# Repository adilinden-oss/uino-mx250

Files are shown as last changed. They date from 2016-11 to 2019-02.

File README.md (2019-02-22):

## \*uino-mx250

The \*uino-mx250 was designed for my son Mathew. As a mostly though-hole design, it should be easy to assemble even for a beginner.  The only surface mount component is the micro USB connector. Personally I much prefer micro USB over the full sized or mini connector. Unfortunately I was unable to find a through-hole micro USB.  Having the one surface mounted component was a compromise I was willing to take.

The board uses the PIC32MX250F128B which is available in a 28 pin through-hole package and includes an on-board USB peripheral.  The PIC32MX250F128B is supported by [chipKIT Core](http://chipkit.net/wiki/index.php?title=ChipKIT_core) for the [Arduino](https://www.arduino.cc/) development environment.  Select the chipKIT DP32.

### Important Note

PCB have been ordered from SeeedStudio FusionPCB service. There is no working sample yet.

### Licensing

This work is licensed under a Creative Commons Attribution-ShareAlike 3.0 Unported License, CC BY-SA.

You are free to copy, distribute and transmit the work. You must attribute the work in the manner specified by the author or licensor (but not in any way that suggests that they endorse you or your use of the work). you alter, transform, or build upon this work, you may distribute the resulting work only under the same or similar license to this one.  

Please refer to [http://creativecommons.org/licenses/by-sa/3.0/] for the license.

### Credit

The \*uino-mx250 is derived from previous work done by:

- The [chipKIT DP32](https://reference.digilentinc.com/chipkit_dp32/refmanual)
- The [HelvePic32](http://www.mathias-wilhelm.de/arduino/embedded-boards/helvepic32)

### Details

Aside from teaching my son how to solder, the motivation for the \*uino-mx250 was to create a through-hole chipKIT board that can make use of existing shields.  The \*uino-mx250 is intended to operate at 3.3V as this is the operating voltage of the PIC32MX250F128B.

Mostly due to the use of the USB peripheral, the PIC32MX250F128B has less available I/O than the ATmega328P. Some compromises and choices were necessary to map the PIC32MX250F128B I/O to the shield pins.  In particular analog pins A1, A2, A3, A4 and A5 are directly connected to digital pins D12, D10, D11, D9 and D8.  This is important to remember!

PIC32MX250F128B I/O is mapped to shield pins to preserve the special functions of the digital pins.  Thanks to PIC32 mappable peripheral pins I2C, SPI, serial and PWM functions are were they should be. Still, some compromises were necessary, either D3 or D11 can use OC2 for PWM, but not both at the same time.

### Pin Mapping

```
        PIC32MX250F128B                                     Peripheral
D0      SOSCO/RPA4/T1CK/CTED9/PMA1/RA4                      RX1         RxD
D1      TDI/RPB7/CTED3/PMD5/INT0/RB7                        TX1         TxD
D2      PGED3/RPB5/PMD7/RB5
D3      TCK/RPB8/SCL1/CTED10/PMD4/RB8                       OC2         PWM
D4      TDO/RPB9/SDA1/CTED4/PMD3/RB9
D5      SOSCI/RPB4/RB4                                      OC1         PWM
D6      AN11/RPB13/CTPLS/PMRD/RB13                          OC4/5       PWM
D7      AN9/C3INA/RPB15/SCK2/CTED6/PMCS1/RB15

D8  A5  AN5/C1INA/C2INC/RTCC/RPB3/SCL2/RB3 
D9  A4  AN4/C1INB/C2IND/RPB2/SDA2/CTED13/RB2                OC4/5       PWM
D10 A2  PGED1/AN2/C1IND/C2INB/C3IND/RPB0/RB0                OC3         PWM
D11 A3  PGEC1/AN3/C1INC/C2INA/RPB1/CTED12/RB1               OC2 DO1     PWM MOSI
D12 A1  PGEC3/VREF-/CVREF-/AN1/RPA1/CTED2/PMD6/RA1          DI          MISO
D13     CVREFOUT/AN10/C3INB/RPB14/SCK1/CTED5/PMWR/RB14      SCK1        SCK

A0      PGED3/VREF+/CVREF+/AN0/C3INC/RPA0/CTED1/PMD7/RA0
A1 D12  PGEC3/VREF-/CVREF-/AN1/RPA1/CTED2/PMD6/RA1
A2 D10  PGED1/AN2/C1IND/C2INB/C3IND/RPB0/RB0
A3 D11  PGEC1/AN3/C1INC/C2INA/RPB1/CTED12/RB1
A4 D9   AN4/C1INB/C2IND/RPB2/SDA2/CTED13/RB2                SDA2        SDA
A5 D8   AN5/C1INA/C2INC/RTCC/RPB3/SCL2/RB3                  SCL2        SCL

```

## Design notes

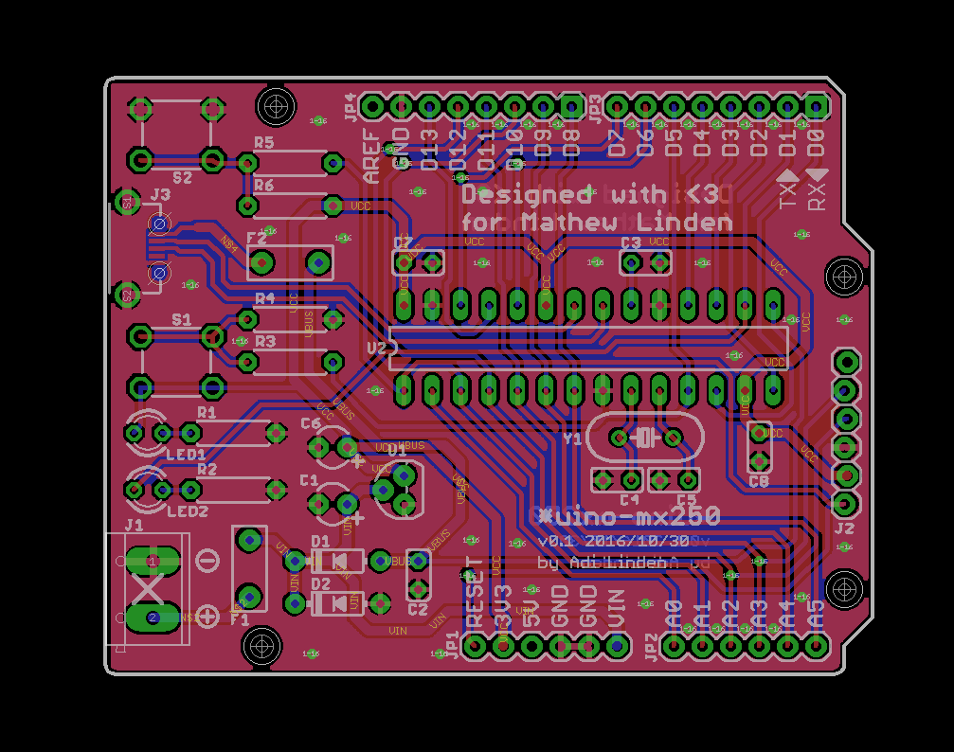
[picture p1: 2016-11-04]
uino-mx250-brd.png

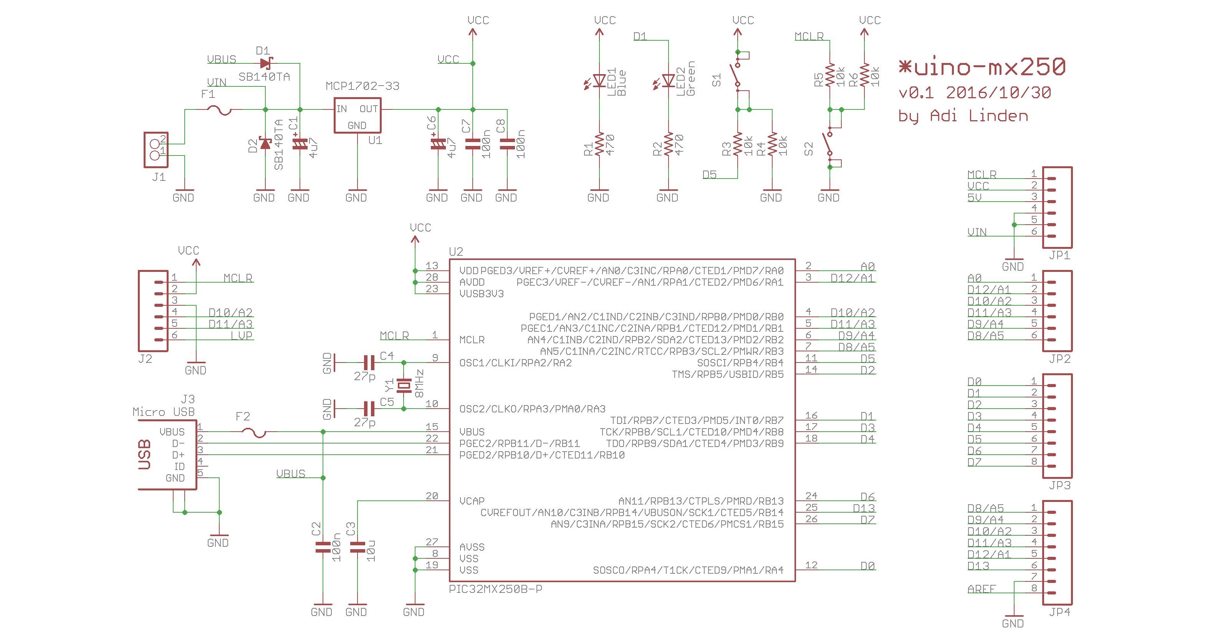
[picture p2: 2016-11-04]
uino-mx250-sch.png

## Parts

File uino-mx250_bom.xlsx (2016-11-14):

Parts | Qty | Value | Manufacturer Part Number | DigiKey Part Number | Package | Description
C1, C6 | 2 | 4u7 | TAP475M010SCS | 478-8841-ND | 2.5mm | 4.7µF ±20% Conformal Coated Tantalum Capacitors 10V Radial 8 Ohm
C2, C7, C8 | 3 | 100n | K104Z15Y5VF5TL2 | BC1160CT-ND | 2.5mm | 0.10µF -20%, +80% 50V Ceramic Capacitor Y5V (F) Radial
C3 | 1 | 10u | FK16X7R1C106K | 445-8348-ND | C025-040X018 | 10µF ±10% 16V Ceramic Capacitor X7R Radial
C4, C5 | 2 | 22p | K220J15C0GF5TL2 | BC1005CT-ND | C025-040X018 | 22pF ±5% 50V Ceramic Capacitor C0G, NP0 Radial
D1, D2 | 2 | 1A | SB140TA | 1655-1514-1-ND | DO-41 | Diode Schottky 40V 1A Through Hole DO-41
F1, F2 | 2 | 400mA | 0ZRC0040FF1E | 507-1335-ND | 5mm | PTC Resettable Fuse 90V 400mA Ih Through Hole Radial, Disc
J1 | 1 | CON_TERMINAL_BLOCK_02-5MM | OSTTC022162 | ED2609-ND | 5mm | 2 Position Wire to Board Terminal Block Horizontal with Board 0.200" (5.08mm) Through Hole
J2 | 1 | Header 1x6 | M20-9990645 | 952-2269-ND | 1X06 | 6 Positions Header, Unshrouded, Breakaway Connector 0.100" (2.54mm) Through Hole Gold
J3 | 1 | Micro USB | 475890001 | WM17143CT-ND | ZX62D-AB-5P8 | USB - micro AB Receptacle Connector 5 Position Surface Mount, Right Angle, Horizontal
JP1, JP2 | 2 | Header 1x6 | PPTC061LFBN-RC | S7004-ND | 1X06 | 6 Position Header Connector 0.100" (2.54mm) Through Hole Tin
JP3, JP4 | 2 | Header 1x8 | PPTC081LFBN-RC | S7006-ND | 1X08 | 8 Position Header Connector 0.100" (2.54mm) Through Hole Tin
LED1 | 1 | Red | 151033RS03000 | 732-5013-ND | LED3MM | Red 621nm LED Indication - Discrete 2V Radial
LED2 | 1 | Green | HLMP1540 | 1080-1046-ND | LED3MM | Green LED Indication - Discrete 2.2V Radial
R1, R2 | 2 | 470 | CF14JT470R | CF14JT470RCT-ND | 0207/7 | RES 470 OHM 1/4W 5% CARBON FILM
R3, R4, R5, R6 | 4 | 10k | CF14JT10K0 | CF14JT10K0CT-ND | 0207/7 | RES 10K OHM 1/4W 5% CARBON FILM
S1, S2 | 2 | Tactile Switch | 1825910-6 | 450-1650-ND | TL1100X | Tactile Switch SPST-NO Top Actuated Through Hole
U1 | 1 | MCP1702-33 | MCP1702-3302E/TO | MCP1702-3302E/TO-ND | TO-92 | Linear Voltage Regulator IC Positive Fixed 1 Output 3.3V 250mA TO-92-3
U2 | 1 | PIC32MX250B-I/SP | PIC32MX270F256B-I/SP | PIC32MX270F256B-I/SP-ND | DIL28-3 | MIPS32® M4K™ PIC® 32MX Microcontroller IC 32-Bit 40MHz 256KB (256K x 8) FLASH 28-SPDIP
Y1 | 1 | 8MHz | ABL-8.000MHZ-B2 | 535-9062-ND | HC49/S | 8MHz ±20ppm Crystal 18pF 80 Ohm -20°C ~ 70°C Through Hole HC49/US

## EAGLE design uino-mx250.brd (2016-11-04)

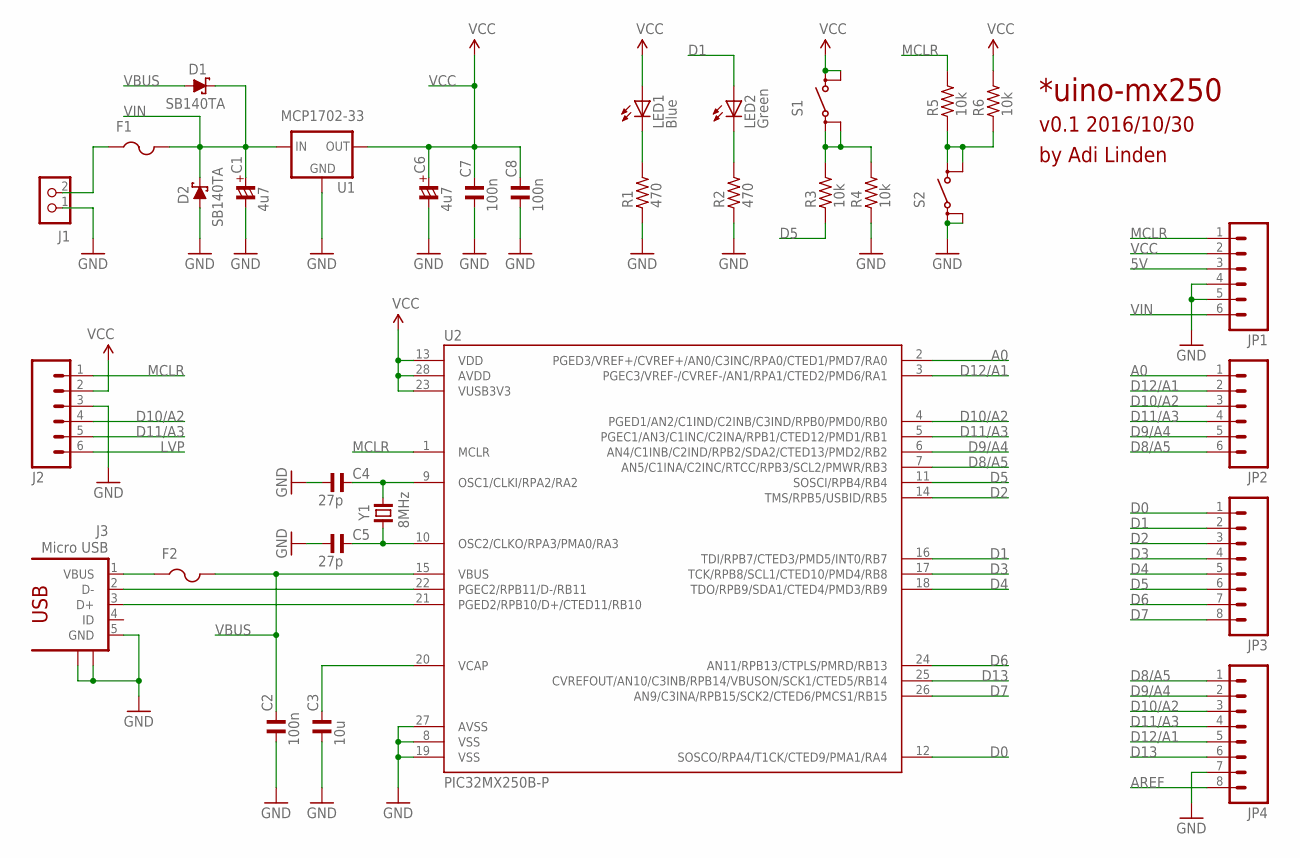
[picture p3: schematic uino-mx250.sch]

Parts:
C1, C6: 4u7; CTT-025-040
C2, C7, C8: 100n; C025-040X018
C3: 10u; C025-040X018
C4, C5: 27p; C025-040X018
D1, D2: SB140TA; DO35-7
F1, F2: FUSE_PTC-TH; PTC
J1: CON_TERMINAL_BLOCK_02-5MM; TERMINAL_BLOCK_2P_5
J2: M06LOCK; 1X06_LOCK
J3: Micro USB; ZX62D-AB-5P8
JP1, JP2: M06SIP; 1X06
JP3, JP4: M081X08; 1X08
LED1: Blue; LED3MM
LED2: Green; LED3MM
R1, R2: 470; 0207/7
R3, R4, R5, R6: 10k; 0207/7
S1, S2: TL1100X
U1: MCP1702-33; TO-92
U2: PIC32MX250B-P; DIL28-3
Y1: 8MHz; HC49/S

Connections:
5V: JP1.3
A0: JP2.1, U2.2 (PGED3/VREF+/CVREF+/AN0/C3INC/RPA0/CTED1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)
AREF: JP4.8
D0: JP3.1, U2.12 (SOSCO/RPA4/T1CK/CTED9/PMA1/RA4)
D1: JP3.2, LED2.A, U2.16 (TDI/RPB7/CTED3/PMD5/INT0/RB7)
D2: JP3.3, U2.14 (TMS/RPB5/USBID/RB5)
D3: JP3.4, U2.17 (TCK/RPB8/SCL1/CTED10/PMD4/RB8)
D4: JP3.5, U2.18 (TDO/RPB9/SDA1/CTED4/PMD3/RB9)
D5: JP3.6, R3.1, U2.11 (SOSCI/RPB4/RB4)
D6: JP3.7, U2.24 (AN11/RPB13/CTPLS/PMRD/RB13)
D7: JP3.8, U2.26 (AN9/C3INA/RPB15/SCK2/CTED6/PMCS1/RB15)
D8/A5: JP2.6, JP4.1, U2.7 (AN5/C1INA/C2INC/RTCC/RPB3/SCL2/PMWR/RB3)
D9/A4: JP2.5, JP4.2, U2.6 (AN4/C1INB/C2IND/RPB2/SDA2/CTED13/PMD2/R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)
D10/A2: J2.4, JP2.3, JP4.3, U2.4 (PGED1/AN2/C1IND/C2INB/C3IND/RPB0/PMD0/R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)
D11/A3: J2.5, JP2.4, JP4.4, U2.5 (PGEC1/AN3/C1INC/C2INA/RPB1/CTED12/PMD1/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)
D12/A1: JP2.2, JP4.5, U2.3 (PGEC3/VREF-/CVREF-/AN1/RPA1/CTED2/PMD6/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)
D13: JP4.6, U2.25 (CVREFOUT/AN10/C3INB/RPB14/VBUSON/SCK1/C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)
GND: C1.-, C2.1, C3.1, C4.1, C5.1, C6.-, C7.1, C8.1, D2.A, J1.1, J2.3, J3.5 (GND), J3.S1, J3.S2, JP1.4, JP1.5, JP4.7, R1.1, R2.1, R4.1, S2.1, S2.2 (P1), U1.1 (GND), U2.8 (VSS), U2.19 (VSS), U2.27 (AVSS)
LVP: J2.6
MCLR: J2.1, JP1.1, R5.2, U2.1 (MCLR)
unnamed: F1.P$1 (1), J1.2
unnamed: F2.P$1 (1), J3.1 (VBUS)
unnamed: LED1.K (C), R1.2
unnamed: LED2.K (C), R2.2
unnamed: R3.2, R4.2, S1.1, S1.2 (P1)
unnamed: R5.1, R6.1, S2.3 (S), S2.4 (S1)
unnamed: C3.2, U2.20 (VCAP)
unnamed: J3.2 (D-), U2.22 (PGEC2/RPB11/D-/RB11)
unnamed: J3.3 (D+), U2.21 (PGED2/RPB10/D+/CTED11/RB10)
unnamed: C4.2, U2.9 (OSC1/CLKI/RPA2/RA2), Y1.2
unnamed: C5.2, U2.10 (OSC2/CLKO/RPA3/PMA0/RA3), Y1.1
VBUS: C2.2, D1.A, F2.P$2 (2), U2.15 (VBUS)
VCC: C6.+, C7.2, C8.2, J2.2, JP1.2, LED1.A, R6.2, S1.3 (S), S1.4 (S1), U1.3 (OUT), U2.13 (VDD), U2.23 (VUSB3V3), U2.28 (AVDD)
VIN: C1.+, D1.C, D2.C, F1.P$2 (2), JP1.6, U1.2 (IN)

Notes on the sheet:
*uino-mx250
v0.1 2016/10/30
by Adi Linden

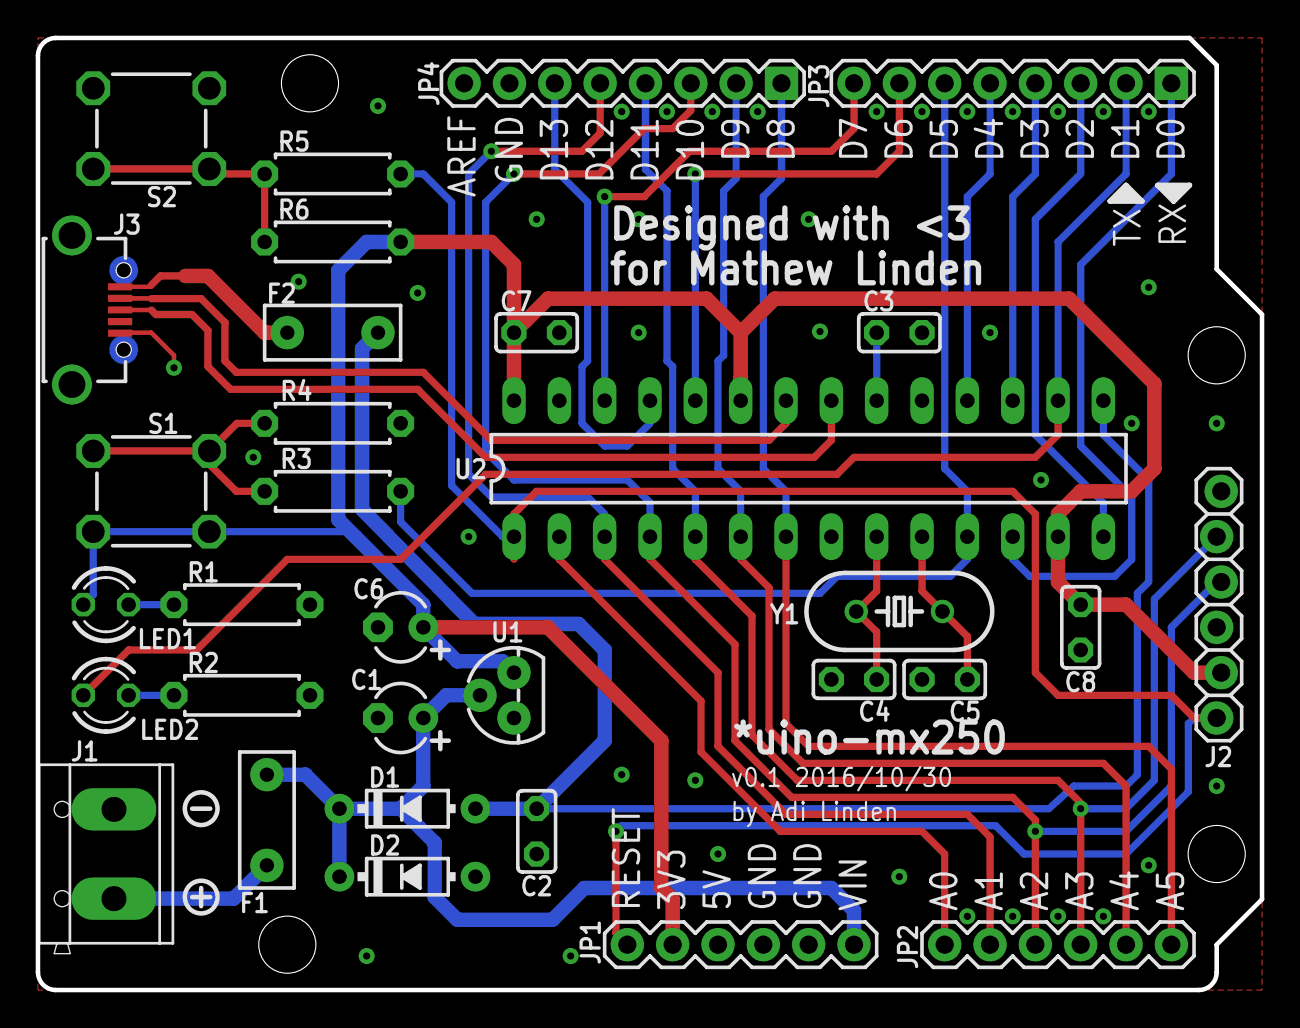
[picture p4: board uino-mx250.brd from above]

Board: 2 copper layers, 68.6 x 53.3 mm, 32 parts (0 on the bottom side), 31 nets.

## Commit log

2016-10-29 Added templates to build uino-mx250.
    [arduino_shield.brd, arduino_shield.sch]
2016-10-30 First working cut.
    [arduino_shield.brd, arduino_shield.sch, uino-mx250.brd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]
2016-10-30 Adjusted power input layout.
    [uino-mx250.brd]
2016-10-31 Created/updated Eagle project. Added .gitignore.
    [uino-mx250.brd]
2016-10-31 Some minor final changes.
    [uino-mx250.brd, uino-mx250.sch]
2016-10-31 Ran cam to generate gerber.
2016-11-04 Added values. Added png files.
    [uino-mx250.brd, uino-mx250.sch]
2016-11-14 Added BOM.
    [uino-mx250_bom.xlsx]

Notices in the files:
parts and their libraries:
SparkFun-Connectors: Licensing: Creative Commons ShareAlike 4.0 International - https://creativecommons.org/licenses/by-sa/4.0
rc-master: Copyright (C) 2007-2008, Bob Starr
